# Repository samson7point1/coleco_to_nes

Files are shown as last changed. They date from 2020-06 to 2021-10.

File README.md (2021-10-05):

# ColecoVision to NES Controller PCB Replacement
This PCB is designed to be swapped out with that of a standard NES controller to allow you to use it with a ColecoVision game console.  As this is a drop-in replacement, there is no need to modify or damage any of the original components of the NES controller.
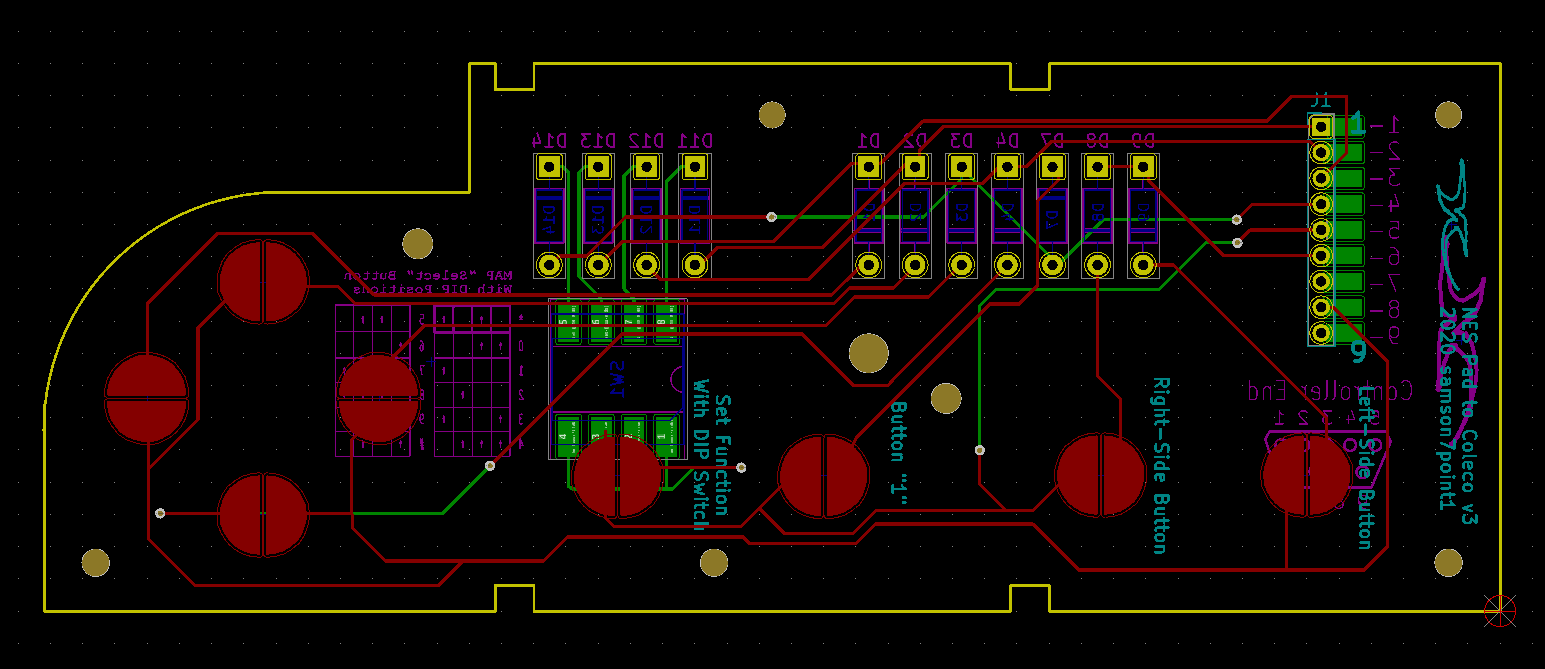
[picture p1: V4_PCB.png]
V4 PCB


## Bill of Materials
* 1 x DE9 Joystick cable (https://console5.com/store/atari-sega-commodore-coleco-msx-6-1-8m-joystick-controller-project-repair-cable-cord.html)
* 11 x 1N4148 Switching Diodes (https://www.mouser.com/ProductDetail/512-1N4148)
* 1 x 4 Position, Low-Profile DIP switch (https://www.mouser.com/ProductDetail/653-A6S-4104-H)
* 1 x OEM NES Control Pad (First Party NES Classic Control Pads may also work)

The board populated (Note the DIP positions have set the Select button to "5"):
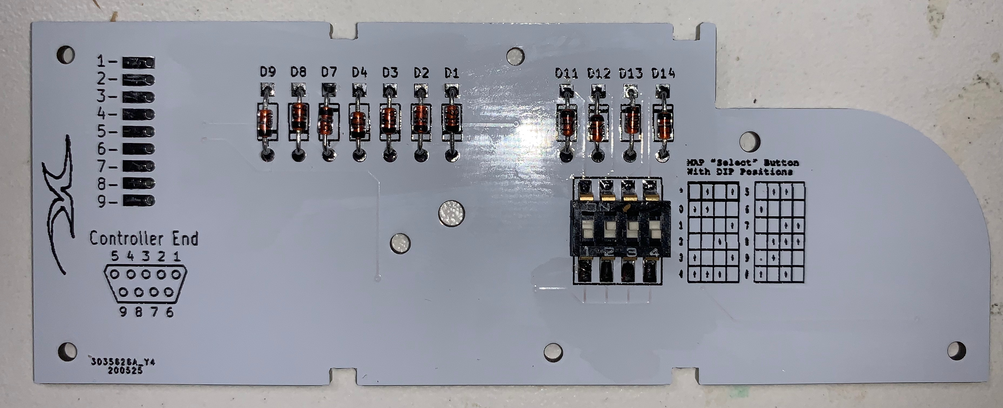
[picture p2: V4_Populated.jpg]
V4 Populated


The board wired and installed:
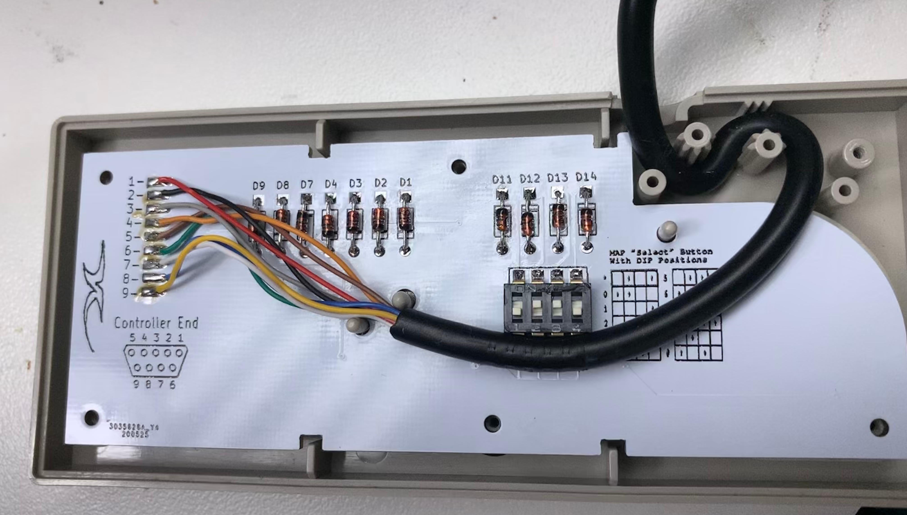
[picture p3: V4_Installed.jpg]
V4 Installed


## Notes / Features
* I reversed the left and right fire buttons from the ColecoVision controller so that the NES "B" button corresponds with the right fire button, and the NES "A" button corresponds with the left.  I initially did this because it made Donkey Kong play closer to the NES version, but I found overall it also worked better for nearly every game I tried.
* The NES "Start" button is mapped to the number pad's "1" button because almost every game requires pressing "1" to start.
* The NES "Select" button can be mapped with the DIP switch on the back

[Test Video - click link then select "View Raw"](TESTING.MOV)
## Mapping the "Select Button"

A handful of games require you to press some button other than "1" to start - for example Mario Bros. requires that you use "5" to add credits before you can play.  Because of this I thought it would be useful if you could just pick which button you want "Select" to imitate.  The settings are actually printed on the PCB, but I thought I'd include them here for reference.

| CV Button | 1 | 2 | 3 | 4 |
|---|---|---|---|---|
| * | | ↑ | | ↑ |
| 0 | ↑ | ↑ | | |
| 1 | | | | ↑ |
| 2 | | | ↑ | |
| 3 | ↑ | | | ↑ |
| 4 | ↑ | ↑ | ↑ | |
| 5 | | ↑ | ↑ | |
| 6 | ↑ | | | |
| 7 | | | ↑ | ↑ |
| 8 | | ↑ | ↑ | ↑ |
| 9 | | ↑ | | |
| # | ↑ | | ↑ | |

## License
This work is licensed under a [Creative Commons Attribution-NonCommercial-ShareAlike 4.0 International License](http://creativecommons.org/licenses/by-nc-sa/4.0/).

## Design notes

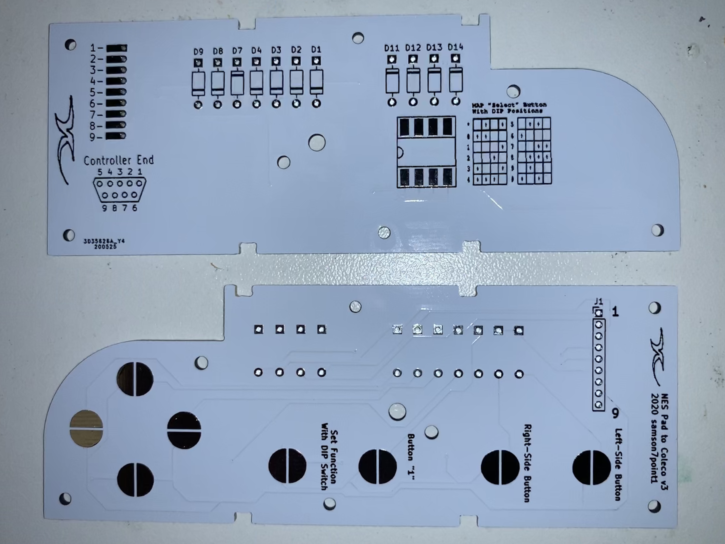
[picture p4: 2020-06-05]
V4_Unpopulated.jpg

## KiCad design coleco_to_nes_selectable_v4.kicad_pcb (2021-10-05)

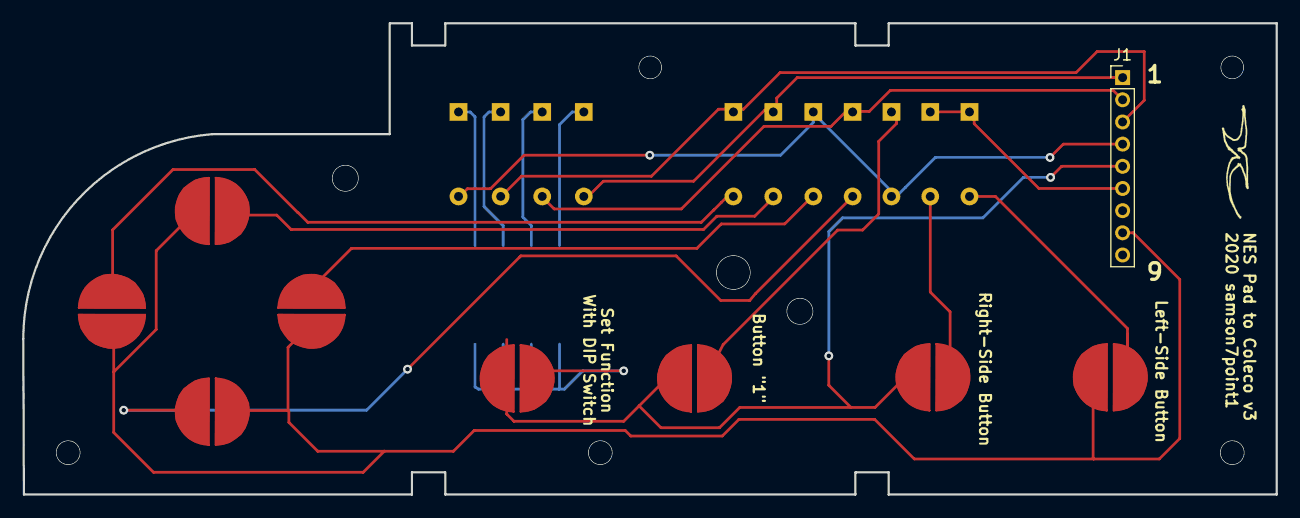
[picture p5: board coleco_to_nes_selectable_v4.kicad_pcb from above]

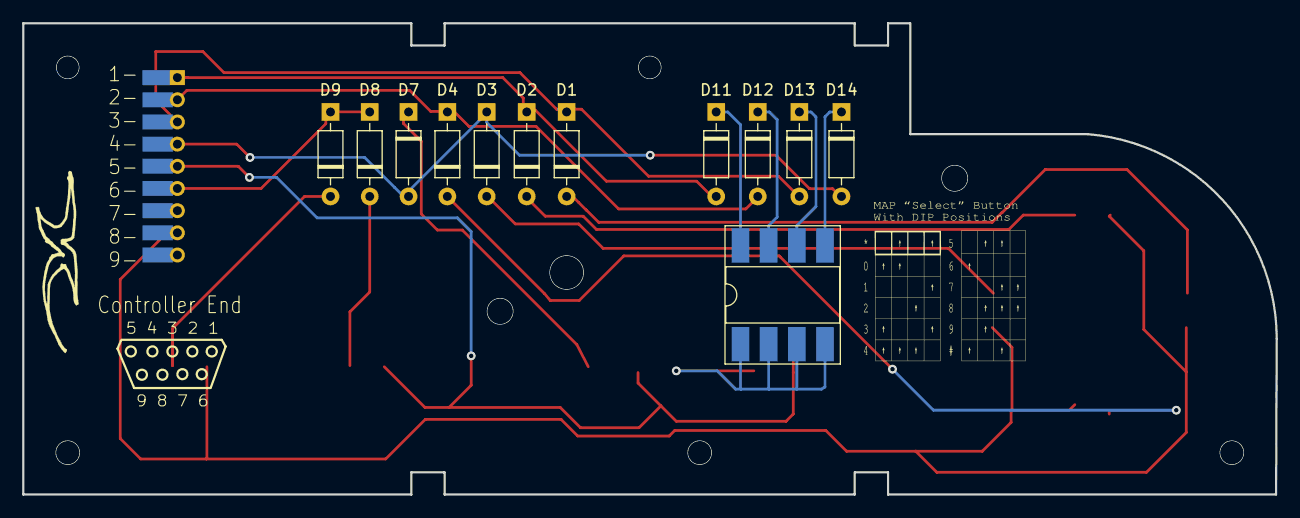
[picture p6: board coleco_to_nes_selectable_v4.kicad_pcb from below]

Board: 2 copper layers, 113.1 x 42.5 mm, 21 parts (12 on the bottom side), 19 nets.

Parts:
Button-1: SW_Push; Contact_Pad_Vertical_Split
Button-*1: SW_Push; Contact_Pad_Vertical_Split
Button-Side-L1: SW_Push; Contact_Pad_Vertical_Split
Button-Side-R1: SW_Push; Contact_Pad_Vertical_Split
D1, D2, D3, D4, D8, D9: DIODE; D_DO-35_SOD27_P7.62mm_Horizontal_reverse_polarity
D7, D11, D12, D13, D14: DIODE; D_DO-35_SOD27_P7.62mm_Horizontal
D-Down1: SW_Push; Contact_Pad_Vertical_Split
D-Left1: SW_Push; Contact_Pad_Vertical_Split
D-Right1: SW_Push; Contact_Pad_Vertical_Split
D-Up1: D-Up; Contact_Pad_Vertical_Split
J1: Conn_01x09_Male; PinHeader_1x09_P2.00mm_Vertical_With_Pads
SW1: SW_DIP_x04; DIP-8_W8.89mm_SMDSocket_LongPads

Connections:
unnamed: Button-1.1, D7.1
unnamed: Button-*1.1, SW1.1, SW1.2, SW1.3, SW1.4
unnamed: Button-1.2, Button-*1.2, Button-Side-R1.1, J1.5
unnamed: Button-Side-L1.1, D-Down1.1, D-Left1.1, D-Right1.1, D-Up1.1, J1.8
unnamed: Button-Side-L1.2, D9.2
unnamed: Button-Side-R1.2, D8.2
unnamed: D1.1, D13.2, J1.3
unnamed: D8.1, D9.1, J1.6
unnamed: D11.1, SW1.8
unnamed: D2.1, D11.2, J1.1
unnamed: D12.1, SW1.7
unnamed: D4.1, D12.2, J1.2
unnamed: D13.1, SW1.6
unnamed: D14.1, SW1.5
unnamed: D3.1, D7.2, D14.2, J1.4
unnamed: D4.2, D-Down1.2
unnamed: D1.2, D-Left1.2
unnamed: D3.2, D-Right1.2
unnamed: D2.2, D-Up1.2

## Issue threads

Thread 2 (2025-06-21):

How to change left and right fire buttons to original Colecovision configuration.

lostbears, 2025-06-21:
Hello.  Sorry for posting this here.  How can I reverse the left and right fire buttons (B & A) so that are the same configuration as the Colecovision controller?

Thank you very much for creating this pcb.

samson7point1, 2025-06-21:
Probably the easiest way would be to switch them at d8 and d9. When you install the diodes, wire the bottom leg of d8 to the bottom via for d9, and vice-versa for d9. You’ll have to either cross them over each other or leave a long lead on one of them, but that should do it.

lostbears, 2025-06-22:
Thank you for the quick reply.  I followed your instructions and unfortunately the A and B buttons did not change.  From what I can tell, the right side of the pads for both the A and B buttons go to D8 and D9 and both of the upper through holes for those diodes are common to controller pin 6.  The diode orientation looks to be the same for both D8 and D9 also.

Any other suggestions?

Thanks again.

samson7point1, 2025-06-23:
Gah, you're right.  Sorry I made you fuss with the diodes for no good reason.  I probably shouldn't have eyeballed the gerber from my phone, lol.  I had it backwards, it's the left pad that needs to be re-routed.  You basically need to cut the trace that leads to the left pad of each button then solder in a bodge that connects the left (B) button to pin 8 and the right (A) button to pin 5.  I can't seem to find the original kicad_sch file for this :( or I would upload an alternate for you.

lostbears, 2025-06-23:
Thank you once again for your help.  If you find the the kicad file and can upload an alternate version that would be fantastic.

samson7point1, 2025-06-23:
Man it has been a minute since I've used Kicad, but I've uploaded an alternate version of the PCB that *should* flip the buttons the way you want.  I haven't tested it, of course, but I expect you can test it with bodge wires first, then roll out a new PCB if it works for you.

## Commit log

2021-10-05 Fix "edge not closed" warnings on PCB
    [coleco_to_nes_selectable_v4.kicad_pcb]
2025-06-23 Added an alternate version where the left and right buttons on the NES pad match the orientation of the triggers on the Coleco controller - the default design reverses this.
